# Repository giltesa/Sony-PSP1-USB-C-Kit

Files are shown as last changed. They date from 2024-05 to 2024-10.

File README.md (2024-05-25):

# Sony PSP 1 USB-C

The **Sony PSP 1: USB-C** is a board that allows to replace the original charging connector for a modern and standard **USB-C**.

**If your original connector is too old or damaged** and you need a new one, or **if you would like to charge your Sony PSP with a standard USB-C charger**, like the charger of your phone, laptop, you can with this board.

This board is compatible with this model:

*   Sony PSP 1000

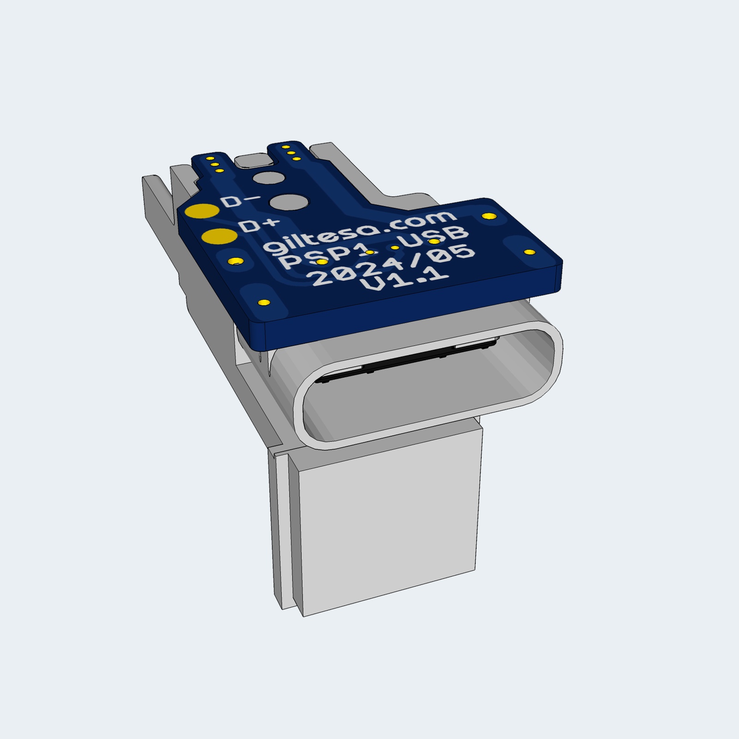
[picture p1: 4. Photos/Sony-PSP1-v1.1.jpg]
Sony-PSP-USB-C


## Would you like it?

https://shop.giltesa.com/product/sony-psp-1000-usb-c-kit/

## More

- [giltesa.com](https://giltesa.com "giltesa.com")
- [twitter.com](https://twitter.com/giltesa "twitter.com")

## License

This project is licensed under a **Creative Commons** license:
**[Attribution-NonCommercial-ShareAlike 4.0 International (CC BY-NC-SA 4.0) ](https://creativecommons.org/licenses/by-nc-sa/4.0/)**

Check the [LICENSE.md](LICENSE.md) for more information.

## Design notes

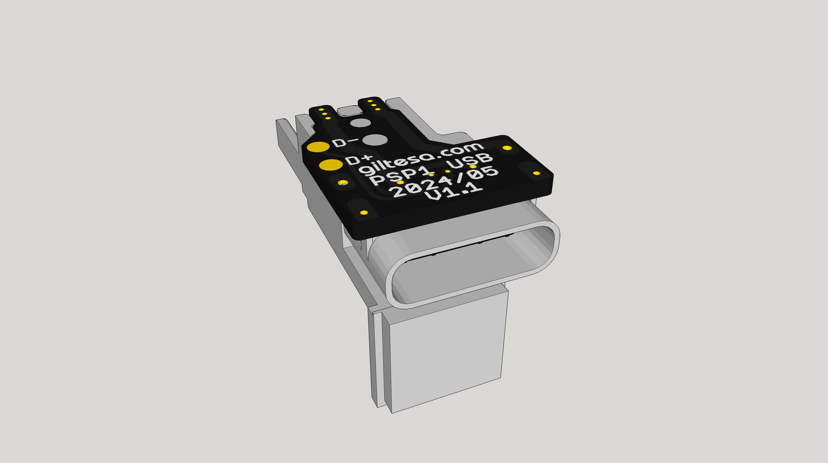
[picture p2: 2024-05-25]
2. Renders, 3D models/Plastic holder/Sony PSP 1000 v1.1.png

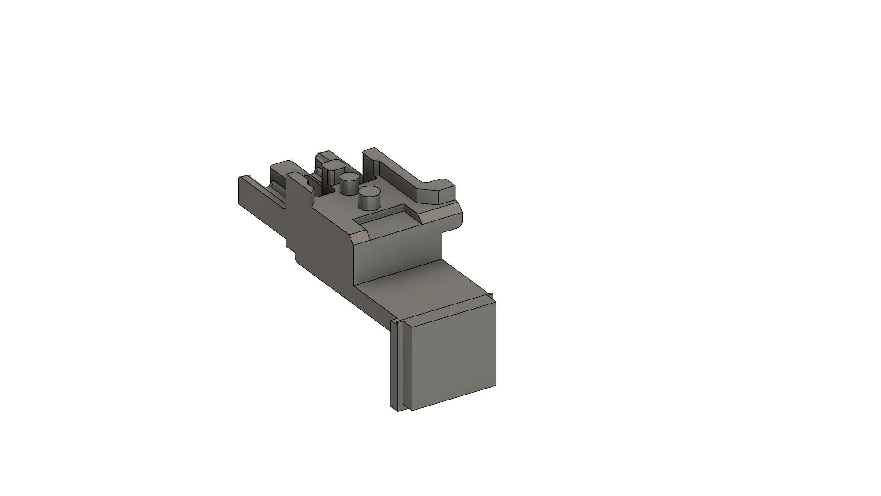
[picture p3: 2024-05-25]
2. Renders, 3D models/Plastic holder/Sony PSP 1000 v29_1.png

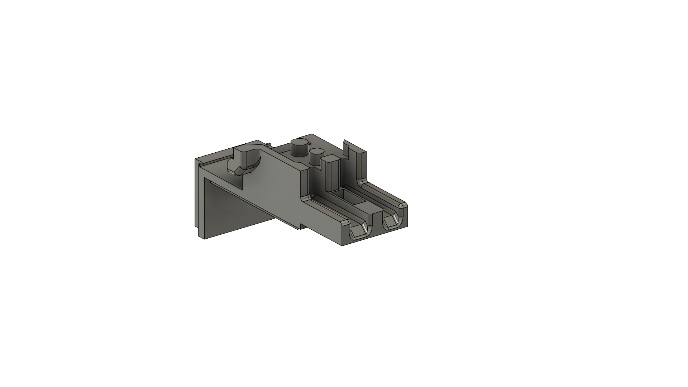
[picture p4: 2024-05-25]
2. Renders, 3D models/Plastic holder/Sony PSP 1000 v29_2.png

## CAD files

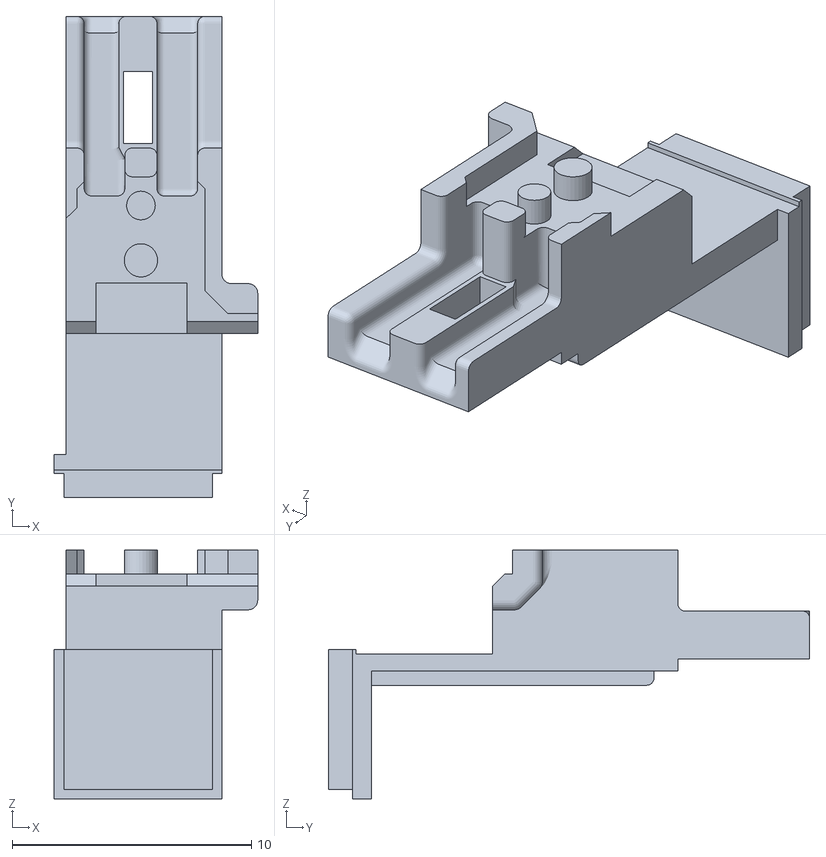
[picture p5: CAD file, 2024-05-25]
2. Renders, 3D models/Plastic holder/Sony PSP 1000 v29.stl
8.50 x 20.1 x 10.4

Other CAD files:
2. Renders, 3D models/Plastic holder/Sony PSP 1000 v29.f3d
2. Renders, 3D models/Sony PSP 1000 v1.0.skp
2. Renders, 3D models/Sony PSP 1000 v1.1.skp
2. Renders, 3D models/Sony PSP 1000 v2.0.skp
2. Renders, 3D models/Sony PSP 1000 v2.1.skp

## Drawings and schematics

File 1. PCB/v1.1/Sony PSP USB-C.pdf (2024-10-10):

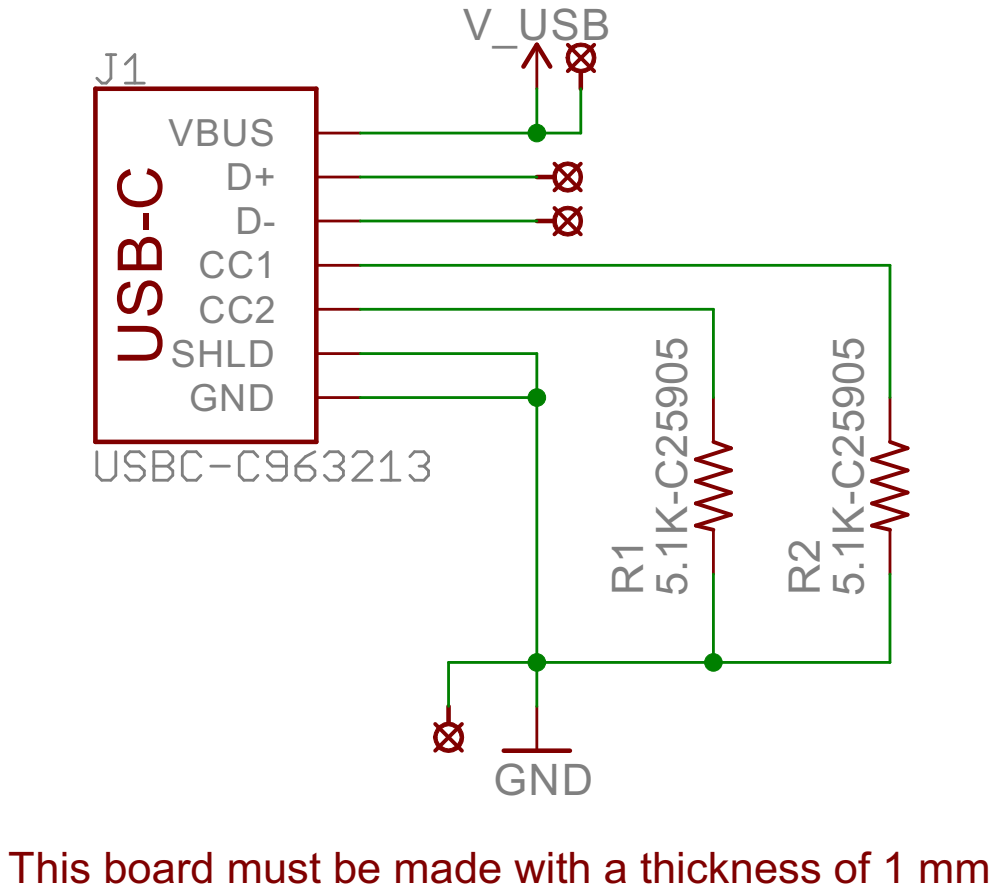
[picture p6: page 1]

This board must be made with a thickness of 1 mm

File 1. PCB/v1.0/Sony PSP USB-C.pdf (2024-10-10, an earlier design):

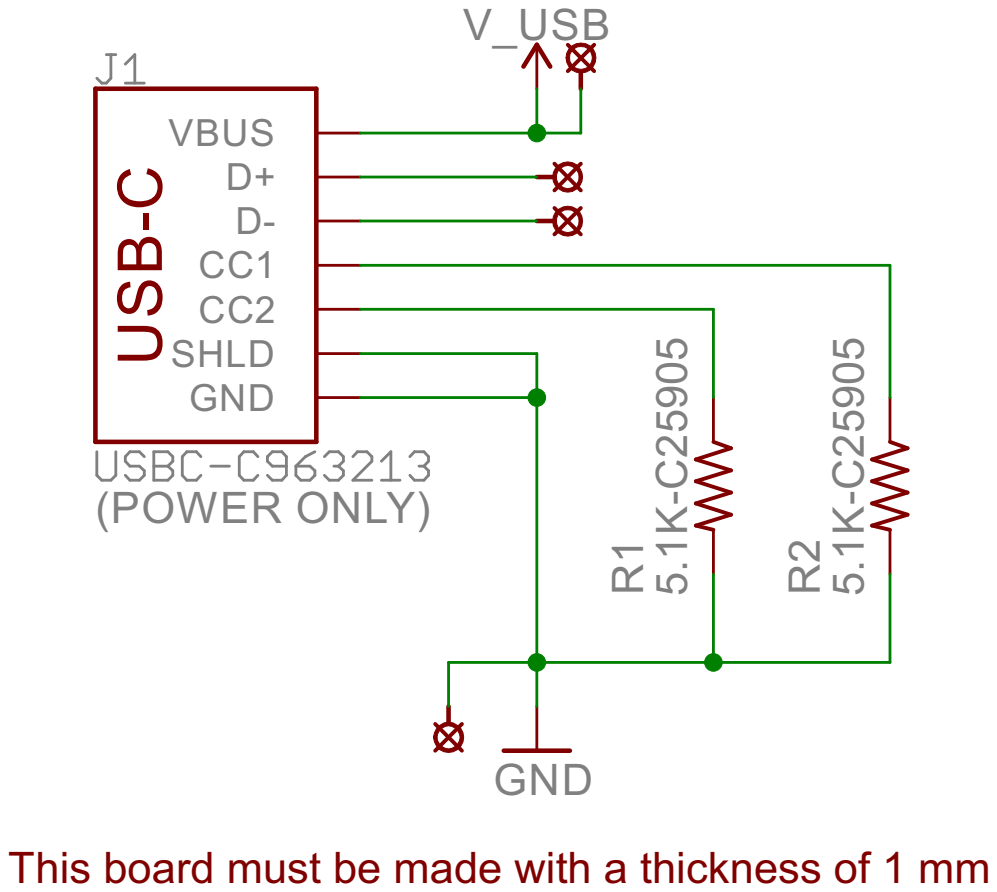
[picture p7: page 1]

This board must be made with a thickness of 1 mm

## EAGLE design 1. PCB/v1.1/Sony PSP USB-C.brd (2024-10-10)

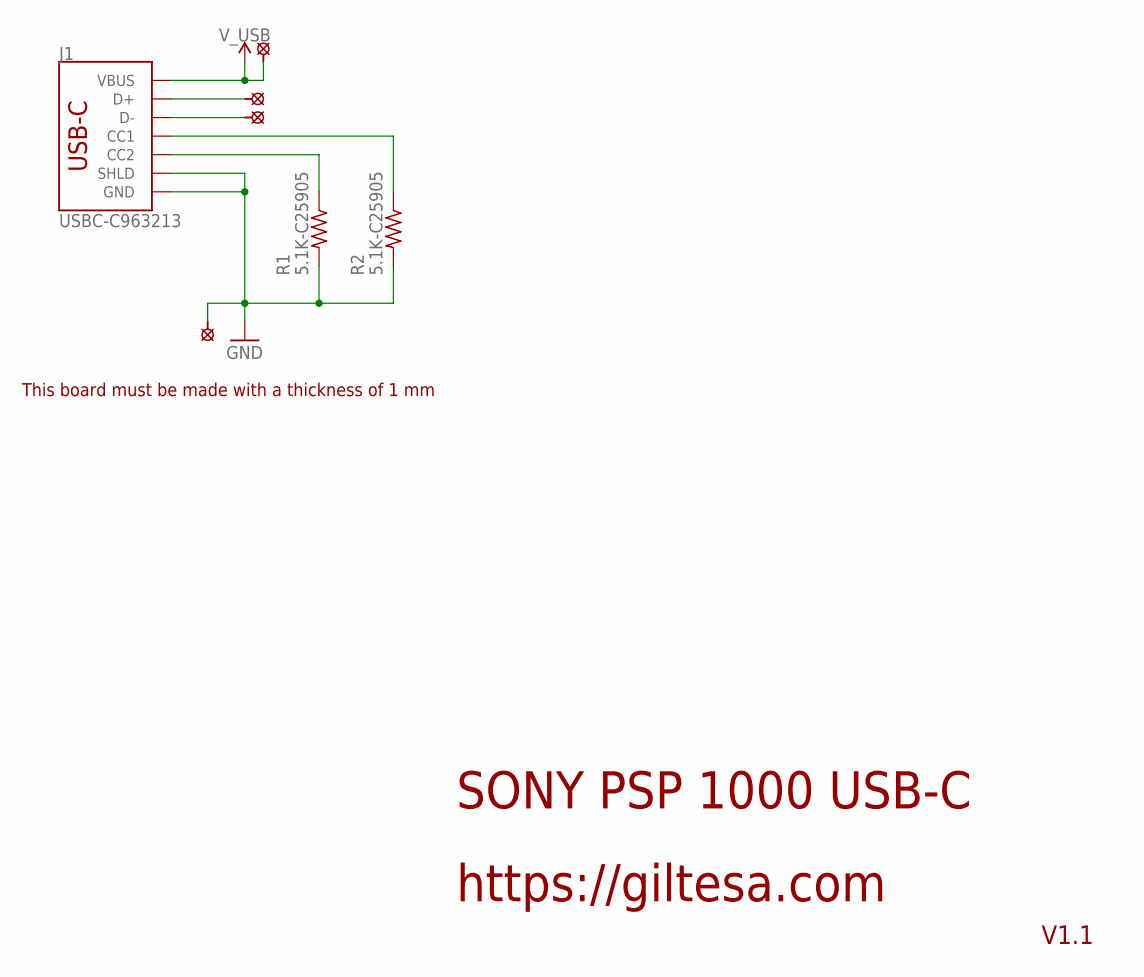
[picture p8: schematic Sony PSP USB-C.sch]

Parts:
J1: USBC-C963213; USB-C_18P_SLIM_GT-USB-7025
R1, R2: 5.1K-C25905; R0402
U$1, U$3: SOLDER_PAD_PSP_1000; PSP_1000_PAD
U$5, U$6: SOLDER_PAD-1.2; SOLDER_PAD_1.2

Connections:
CC1: J1.A5-CC1 (CC1), R2.1
CC2: J1.B5-CC2 (CC2), R1.1
D+: J1.A6-DP1 (D+), J1.B6-DP2 (D+), U$5.P$1
D-: J1.A7-DN1 (D-), J1.B7-DN2 (D-), U$6.P$1
GND: J1.A1-GND (GND), J1.A12-GND (GND), J1.B1-GND (GND), J1.B12-GND (GND), J1.GND1 (GND), J1.GND2 (GND), J1.SHLD1 (SHLD), J1.SHLD2 (SHLD), J1.SHLD3 (SHLD), J1.SHLD4 (SHLD), R1.2, R2.2, U$1.1
V_USB: J1.A4-VBUS (VBUS), J1.A9-VBUS (VBUS), J1.B4-VBUS (VBUS), J1.B9-VBUS (VBUS), U$3.1

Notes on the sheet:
SONY PSP 1000 USB-C
https://giltesa.com
V1.1
This board must be made with a thickness of 1 mm

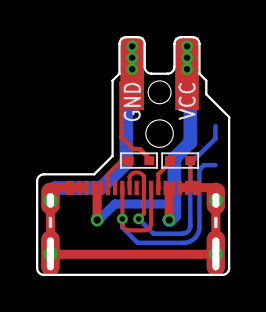
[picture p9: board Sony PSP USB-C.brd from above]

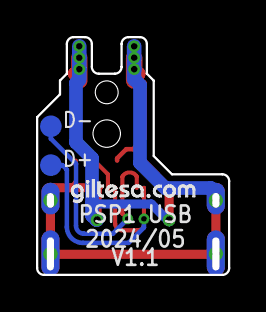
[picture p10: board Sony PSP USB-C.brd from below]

Board: 2 copper layers, 10.7 x 13.2 mm, 8 parts (3 on the bottom side), 6 nets.

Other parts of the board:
U$11: GILTESA.COM_MASK_7MM

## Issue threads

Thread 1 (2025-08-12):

Installation help

Stevegrimeszz, 2025-08-12:
Do I need to solder a ground wire on the psp 1000?

giltesa, 2025-08-12:
Hello,

You need to solder the original power cable to the new board. That is the
GND and VCC pin.
https://github.com/giltesa/Sony-PSP1-USB-C-Kit/tree/master/3.%20Documentation

Kind regards,
giltesa

El mar, 12 ago 2025 a las 5:37, Stevegrimeszz ***@***.***>)
escribió:

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

giltesa, 2025-08-12:
Hello,

I hadn’t understood that you were referring to the data connection, and not
to the power supply.
For the data connection, you need to solder 3 wires: D+, D-, and VCC. GND
is not necessary. With a multimeter in continuity mode, you can verify that
the GND pad on the usb-c board has continuity with the GND pads on the
MiniUSB.

Does the computer still recognize the console if you connect it with a
MiniUSB cable? Maybe there is a short between pins.

Kind regards,
giltesa

El mar, 12 ago 2025 a las 13:20, Stevegrimeszz ***@***.***>)
escribió:

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

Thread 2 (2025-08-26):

Help finding correct USBC port

copywizard, 2025-08-26:
Hello firstly thanks a lot for this great project.
I had pcbway make a few of these boards using your Gerber file.
But I can't for the life of me find out which type of USBC port is used? I have a box of 10 different usbc ports and non fit this pcb.

Can you please link me the correct 16/18 pin USBC port so I can order them?

giltesa, 2025-08-26:
Hello,

The schematic includes the serial numbers of each component. All the parts
are from LCSC.

Kind regards,
giltesa

El mar, 26 ago 2025 a las 20:16, copywizard ***@***.***>)
escribió:

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

Closed 2025-08-26.

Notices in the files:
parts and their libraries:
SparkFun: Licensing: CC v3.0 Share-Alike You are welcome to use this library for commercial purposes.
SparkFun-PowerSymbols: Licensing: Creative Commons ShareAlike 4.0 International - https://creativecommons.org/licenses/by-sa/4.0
